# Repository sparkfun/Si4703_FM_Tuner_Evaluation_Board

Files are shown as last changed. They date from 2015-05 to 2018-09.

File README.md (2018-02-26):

SparkFun FM Tuner Evaluation Board - Si4703
===========================================

SparkFun FM Tuner Evaluation Board - Si4703  

[*SparkFun FM Tuner Evaluation Board - Si4703 (WRL-12938)*](https://www.sparkfun.com/products/12938)

This is an evaluation board for the Silicon Laboratories Si4703 FM tuner chip. Beyond being a simple FM radio, the Si4703 
is also capable of detecting and processing both Radio Data Service (RDS) and Radio Broadcast Data Service (RBDS) information. 

Repository Contents
-------------------
* **/Firmware** - Example code 
* **/Hardware** - Eagle design files (.brd, .sch)
* **/Libraries** - Libraries for use with the Si4703 Evaluation Board
* **/Production** - Production panel files (.brd)

Documentation
--------------
* **[Library](https://github.com/sparkfun/SparkFun_Si4703_Arduino_Library)** - Arduino and Raspberry Pi libraries for the Si4703.
* **[Hookup Guide](https://learn.sparkfun.com/tutorials/si4703-fm-radio-receiver-hookup-guide)** - Basic hookup guide for the Si4703.
* **[SparkFun Fritzing repo](https://github.com/sparkfun/Fritzing_Parts)** - Fritzing diagrams for SparkFun products.
* **[SparkFun 3D Model repo](https://github.com/sparkfun/3D_Models)** - 3D models of SparkFun products. 

License Information
-------------------
This product is _**open source**_! 

Please review the LICENSE.md file for license information. 

If you have any questions or concerns on licensing, please contact techsupport@sparkfun.com.

Distributed as-is; no warranty is given.

- Your friends at SparkFun.

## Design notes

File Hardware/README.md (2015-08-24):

SparkFun Si4703 Evaluation Board Design Files
============================================

The .sch and .brd files hare are Eagle CAD schematic and PCB design files from SparkFun Electronics.
A freeware version of Eagle can be found [here](http://www.cadsoftusa.com/download-eagle/freeware/). 

License
---------
This product is open source! 
The hardware is released under [Creative Commons ShareAlike 4.0 International](https://creativecommons.org/licenses/by-sa/4.0/).

Please use, reuse, and modify these files as you see fit. Please maintain attribution to SparkFun Electronics and release anything derivative under the same license.

Distributed as-is; no warranty is given.

- Your friends at SparkFun.

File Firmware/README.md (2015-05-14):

SparkFun Si4703 Firmware
===================================

* **Si4703_Example** - Arduino example

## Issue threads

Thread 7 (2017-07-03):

Polling during seek can impair receiver performance when using the internal oscillator

bigjosh, 2017-07-03:
From datasheet rev1.1...

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

Here is the polling code...
https://github.com/sparkfun/Si4703_FM_Tuner_Evaluation_Board/blob/master/Libraries/Arduino/src/SparkFunSi4703.cpp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

Ideal solution would be to generate an interrupt on seek completion, but this would add complexity and an extra pin.

Other options for mitigating could include....

* Adding a delay inside the loop so poll at least is not constantly banging on the bus at full blast. Increases code size slightly, and increases latency but a delay value of, say, 100ms likely not noticeable.
* Adding a length parameter to `readRegisters()` to reduce the amount of bus traffic. Since the seek function only needs to check register 0x0a to see if the STC bit is set, no need to read in all the other read registers on every poll. Slightly increases complexity.

LMK thoughts or if you want a PR for either or both.

bigjosh, 2018-02-27:
HI @nseidle !

I ended up forking and implementing both mitigation, but by now my fork is probably too far astray for an easy PR.

BTW, we empirically also found a few more issues with this chip - especially in the initialization timing. The problems are only an issue when you are using a lot of these chips and turning them on and off frequently. My current init code is here if you want to have a look...

https://github.com/bigjosh/Firmware/blob/no-led-pwm/Firmware/main.c#L489

It is a little messy right now because we were making changes on the fly as problems showed up in the field, but it has been stable for a few months now so I should clean it up.

I also ended up rewriting the TWI stuff from scratch to get everything to fit into an ATTINY25 (2K flash). That code is rock solid and much smaller and simpler than the old Atmel stuff....
https://github.com/bigjosh/Firmware/blob/no-led-pwm/Firmware/USI_TWI_Master.c

LMK if you are interested in any of this stuff and we can figure out the best way to get things merged.

nseidle, 2018-03-05:
What a super cool project! http://www.thepublicrad.io/

I agree - you have gone very hard core for a variety of good reasons. I would enjoy your improvements but you're rightly focused on ATtiny shoe-horning.

If you have a top 2 fix list that you could incorporate back into our lib that would be my ideal. But I imagine you've got other important things to work on. I'll keep this issue open so others can find your work.

Grahldg, 2018-09-12:
The latest release uses STC interrupts on GPIO2.  Suggestions from @bigjosh above to add a delay or only poll the appropriate register can also be used if anyone would like to increase tuning accuracy without the use of additional pin.

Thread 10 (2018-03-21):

No need the wait after Wire.requestFrom().

Koepel, 2018-03-21:
The line `while(Wire.available() < 32) ;` after the Wire.requestFrom() can be removed in:
- Si4703_FM_Tuner_Evaluation_Board/Firmware/Si4703_Example/Si4703_Example.ino
- Si4703_FM_Tuner_Evaluation_Board/Libraries/Arduino/src/SparkFunSi4703.cpp

When the Wire.requestFrom() returns, the I2C transaction on the bus has completely finished and the received data is waiting in a buffer in the Wire library. There is no need to wait for something.

Grahldg, 2018-09-10:
Hi @Koepel ,

I removed both instances as well as one in the [Arduino Library](https://github.com/sparkfun/SparkFun_Si4703_Arduino_Library).

Closed 2018-09-10.

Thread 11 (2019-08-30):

Seems RDS reading doesn't work with arduino

moznion, 2019-08-30:
Hi,

I've tried to run the `Si4703_Radio_Test` example with the Si4703 break board on Arduino.
It seems sound receiving works certainly, but RDS reading (i.e. send `r` key via serial) doesn't work certainly; it means the `rdsBuffer` is empty. On the other hand, the real radio product can receive the RDS text correctly.
In my investigation, `STATUSRSSI` register's `RDSR` bit **never** be high even if the RDS text is on the wave.

FYI, I've used Si4713 chip as the FM transmitter with this library: https://github.com/adafruit/Adafruit-Si4713-Library

What do you think about this problem?

Incidentally, I modified the library code to change it be suitable to use in Japan. The diff is the following:

```diff
diff --git a/Libraries/Arduino/src/SparkFunSi4703.cpp b/Libraries/Arduino/src/SparkFunSi4703.cpp
index 2e5cd7e..aaa2f44 100644
--- a/Libraries/Arduino/src/SparkFunSi4703.cpp
+++ b/Libraries/Arduino/src/SparkFunSi4703.cpp
@@ -17,12 +17,12 @@ void Si4703_Breakout::powerOn()

 void Si4703_Breakout::setChannel(int channel)
 {
-  //Freq(MHz) = 0.200(in USA) * Channel + 87.5MHz
-  //97.3 = 0.2 * Chan + 87.5
-  //9.8 / 0.2 = 49
-  int newChannel = channel * 10; //973 * 10 = 9730
-  newChannel -= 8750; //9730 - 8750 = 980
-  newChannel /= 10; //980 / 10 = 98
+  // Freq(MHz) = 0.100(in Japan) * Channel + 76.0MHz
+  // 80.0 = 0.1 * Chan + 76.0
+  // 4.0 / 0.1 = 40
+  int newChannel = channel * 10; // 800 * 10 = 8000
+  newChannel -= 7600;            // 8000 - 7600 = 400
+  newChannel /= 10;              // 400 / 10 = 40
@@ -113,7 +114,7 @@ void Si4703_Breakout::readRDS(char* buffer, long timeout)
 //To get the Si4703 inito 2-wire mode, SEN needs to be high and SDIO needs to be low after a reset
 //The breakout board has SEN pulled high, but also has SDIO pulled high. Therefore, after a normal power up
 //The Si4703 will be in an unknown state. RST must be controlled
-void Si4703_Breakout::si4703_init()
+void Si4703_Breakout::si4703_init()
 {
   pinMode(_resetPin, OUTPUT);
   pinMode(_sdioPin, OUTPUT); //SDIO is connected to A4 for I2C
@@ -141,10 +142,12 @@ void Si4703_Breakout::si4703_init()
   si4703_registers[SYSCONFIG1] |= (1<<RDS); //Enable RDS

   si4703_registers[SYSCONFIG1] |= (1<<DE); //50kHz Europe setup
-  si4703_registers[SYSCONFIG2] |= (1<<SPACE0); //100kHz channel spacing for Europe
+  si4703_registers[SYSCONFIG2] |= (1<<SPACE0); //100kHz channel spacing for Japan
+  si4703_registers[SYSCONFIG2] |= (1<<JP_WIDE_BAND);

   si4703_registers[SYSCONFIG2] &= 0xFFF0; //Clear volume bits
   si4703_registers[SYSCONFIG2] |= 0x0001; //Set volume to lowest
+
   updateRegisters(); //Update

   delay(110); //Max powerup time, from datasheet page 13
@@ -184,7 +187,7 @@ byte Si4703_Breakout::updateRegisters() {

   //End this transmission
   byte ack = Wire.endTransmission();
-  if(ack != 0) { //We have a problem!
+  if(ack != 0) { //We have a problem!
     return(FAIL);
   }
@@ -229,8 +232,8 @@ return getChannel();
 int Si4703_Breakout::getChannel() {
   readRegisters();
   int channel = si4703_registers[READCHAN] & 0x03FF; //Mask out e
verything but the lower 10 bits
-  //Freq(MHz) = 0.100(in Europe) * Channel + 87.5MHz
-  //X = 0.1 * Chan + 87.5
-  channel += 875; //98 + 875 = 973
+  // Freq(MHz) = 0.100(in Japan) * Channel + 76.0MHz
+  // X = 0.1 * Chan + 76.0
+  channel += 760; // 40 + 760 = 800
   return(channel);
 }
```

† JP_WIDE_BAND=6

inpatol, 2023-06-18:
Hi, have you found a solution for this? I am having the same problem in argentina.

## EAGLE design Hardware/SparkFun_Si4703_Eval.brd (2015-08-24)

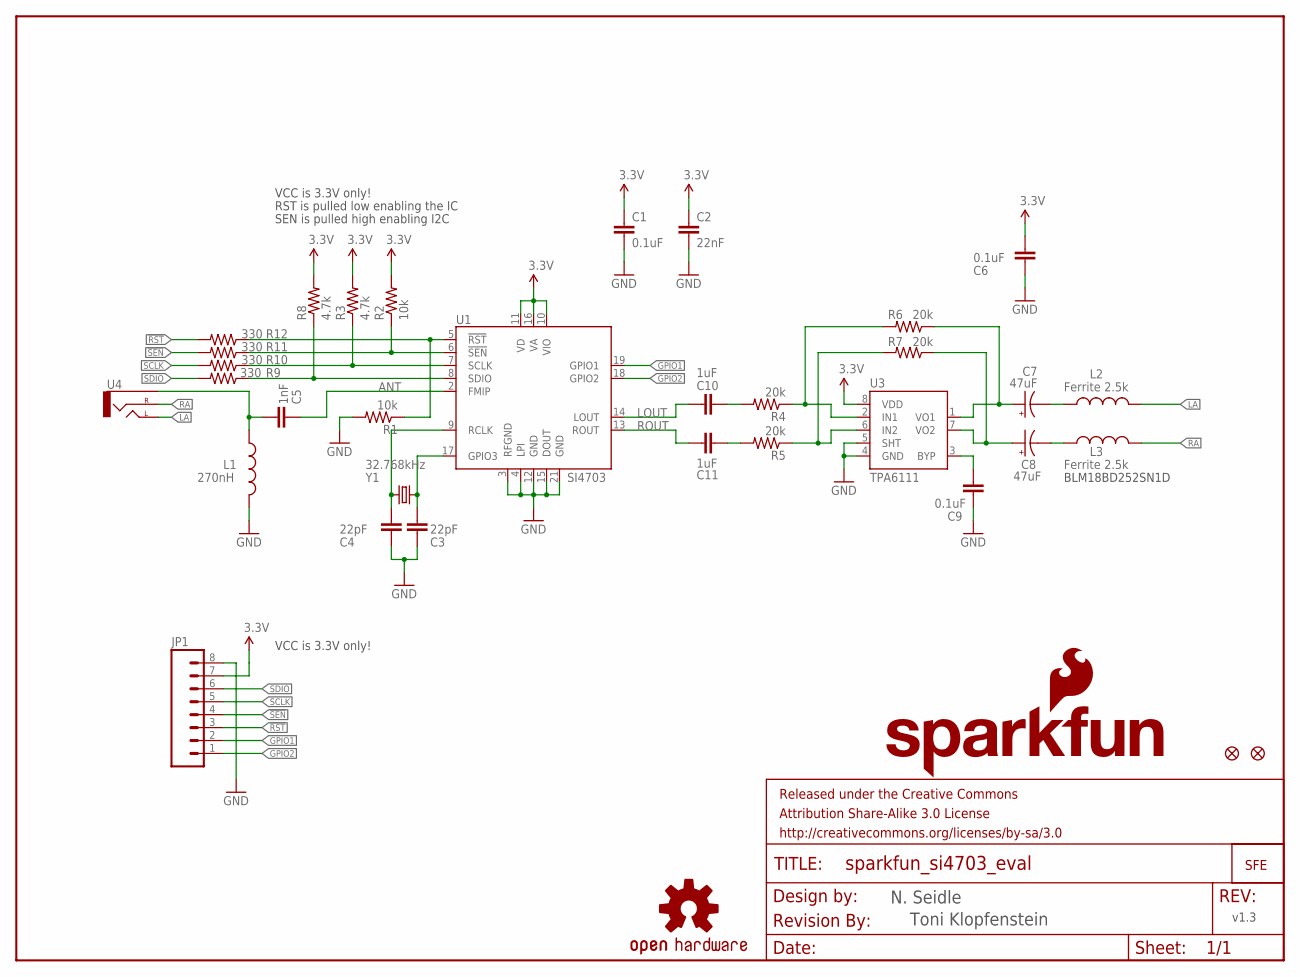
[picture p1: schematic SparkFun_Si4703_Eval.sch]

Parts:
C1, C6, C9: 0.1uF; 0603-CAP
C2: 22nF; 0603-CAP
C3, C4: 22pF; 0603-CAP
C5: 1nF; 0603-CAP
C7, C8: 47uF; EIA3528
C10, C11: 1uF; 0603-CAP
FRAME2: FRAME-LETTER; CREATIVE_COMMONS
JP1: M08; 1X08
JP3: LOGO-SFESK; SFE-LOGO-FLAME
JP4, JP5: FIDUCIAL1X2; FIDUCIAL-1X2
L1: 270nH; 0603
L2, L3: Ferrite 2.5k; 0603
LOGO1: SFE_LOGO_NAME_FLAME.1_INCH; SFE_LOGO_NAME_FLAME_.1
LOGO2: OSHW-LOGOS; OSHW-LOGO-S
R1, R2: 10k; 0603-RES
R3, R8: 4.7k; 0603
R4, R5, R6, R7: 20k; 0603-RES
R9, R10, R11, R12: 330; 0603-RES
U1: SI4703; SI470X
U3: TPA6111; SO08-TIGHT
U4: AUDIO-JACKSMD2; AUDIO-JACK-3.5MM-SMD
U$1: REVISION
Y1: 32.768kHz; CRYSTAL-32KHZ-SMD

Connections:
3.3V: C1.1, C2.1, C6.2, JP1.7, R2.2, R3.2, R8.2, U1.10 (VIO), U1.11 (VD), U1.16 (VA), U3.8 (VDD)
!RST: JP1.3, R12.2
!RST-L: R1.1, R12.1, U1.5 (!RST)
!SEN: JP1.4, R11.2
!SEN-L: R2.1, R11.1, U1.6 (!SEN)
ANT: C5.1, U1.2 (FMIP)
GND: C1.2, C2.2, C3.1, C4.1, C6.1, C9.2, JP1.8, L1.2, R1.2, U1.3 (RFGND), U1.4 (LPI), U1.12 (GND), U1.15 (DOUT), U1.21 (GND), U3.4 (GND), U3.5 (SHT)
GPIO1: JP1.2, U1.19 (GPIO1)
GPIO2: JP1.1, U1.18 (GPIO2)
LA: L2.2, U4.TIP (LEFT)
LOUT: C10.1, U1.14 (LOUT)
unnamed: C4.2, U1.9 (RCLK), Y1.X2 (2)
unnamed: C3.2, U1.17 (GPIO3), Y1.X1 (1)
unnamed: C5.2, L1.1, U4.SLEEVE
unnamed: C7.C (-), L2.1
unnamed: C7.A (+), R6.1, U3.1 (VO1)
unnamed: C8.A (+), R7.1, U3.7 (VO2)
unnamed: C8.C (-), L3.1
unnamed: C9.1, U3.3 (BYP)
unnamed: R4.1, R6.2, U3.2 (IN1)
unnamed: R5.1, R7.2, U3.6 (IN2)
unnamed: C10.2, R4.2
unnamed: C11.2, R5.2
RA: L3.2, U4.RING (RIGHT)
ROUT: C11.1, U1.13 (ROUT)
SCLK: JP1.5, R10.2
SCLK-L: R3.1, R10.1, U1.7 (SCLK)
SDIO: JP1.6, R9.2
SDIO-L: R8.1, R9.1, U1.8 (SDIO)

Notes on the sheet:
VCC is 3.3V only!
N. Seidle
BLM18BD252SN1D
SEN is pulled high enabling I2C
RST is pulled low enabling the IC
v1.3
Toni Klopfenstein

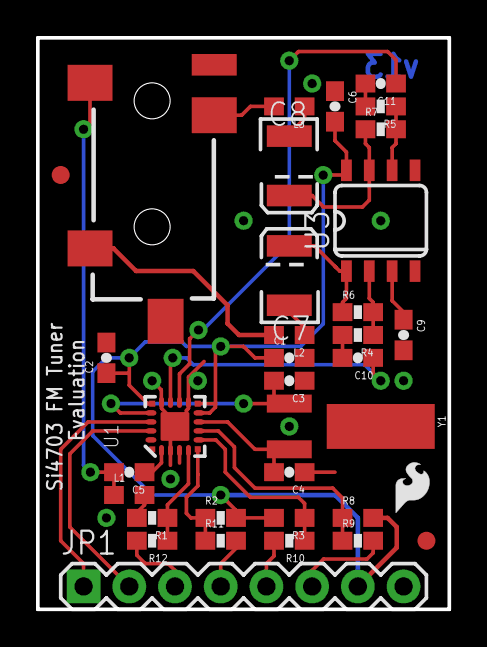
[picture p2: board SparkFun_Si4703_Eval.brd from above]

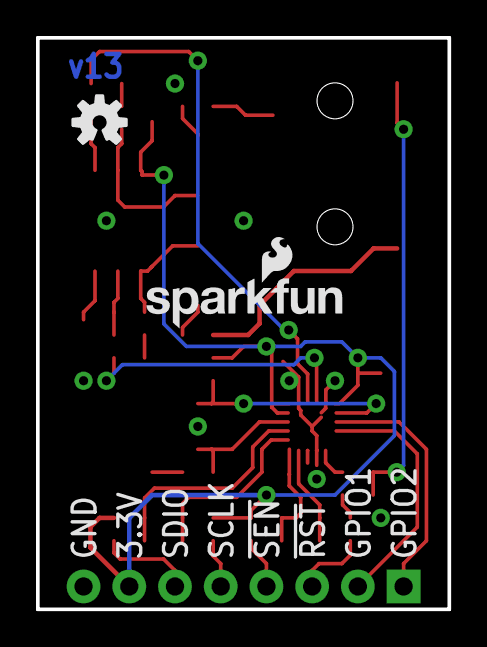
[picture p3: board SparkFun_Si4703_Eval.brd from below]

Board: 2 copper layers, 22.9 x 31.8 mm, 38 parts (2 on the bottom side), 29 nets.

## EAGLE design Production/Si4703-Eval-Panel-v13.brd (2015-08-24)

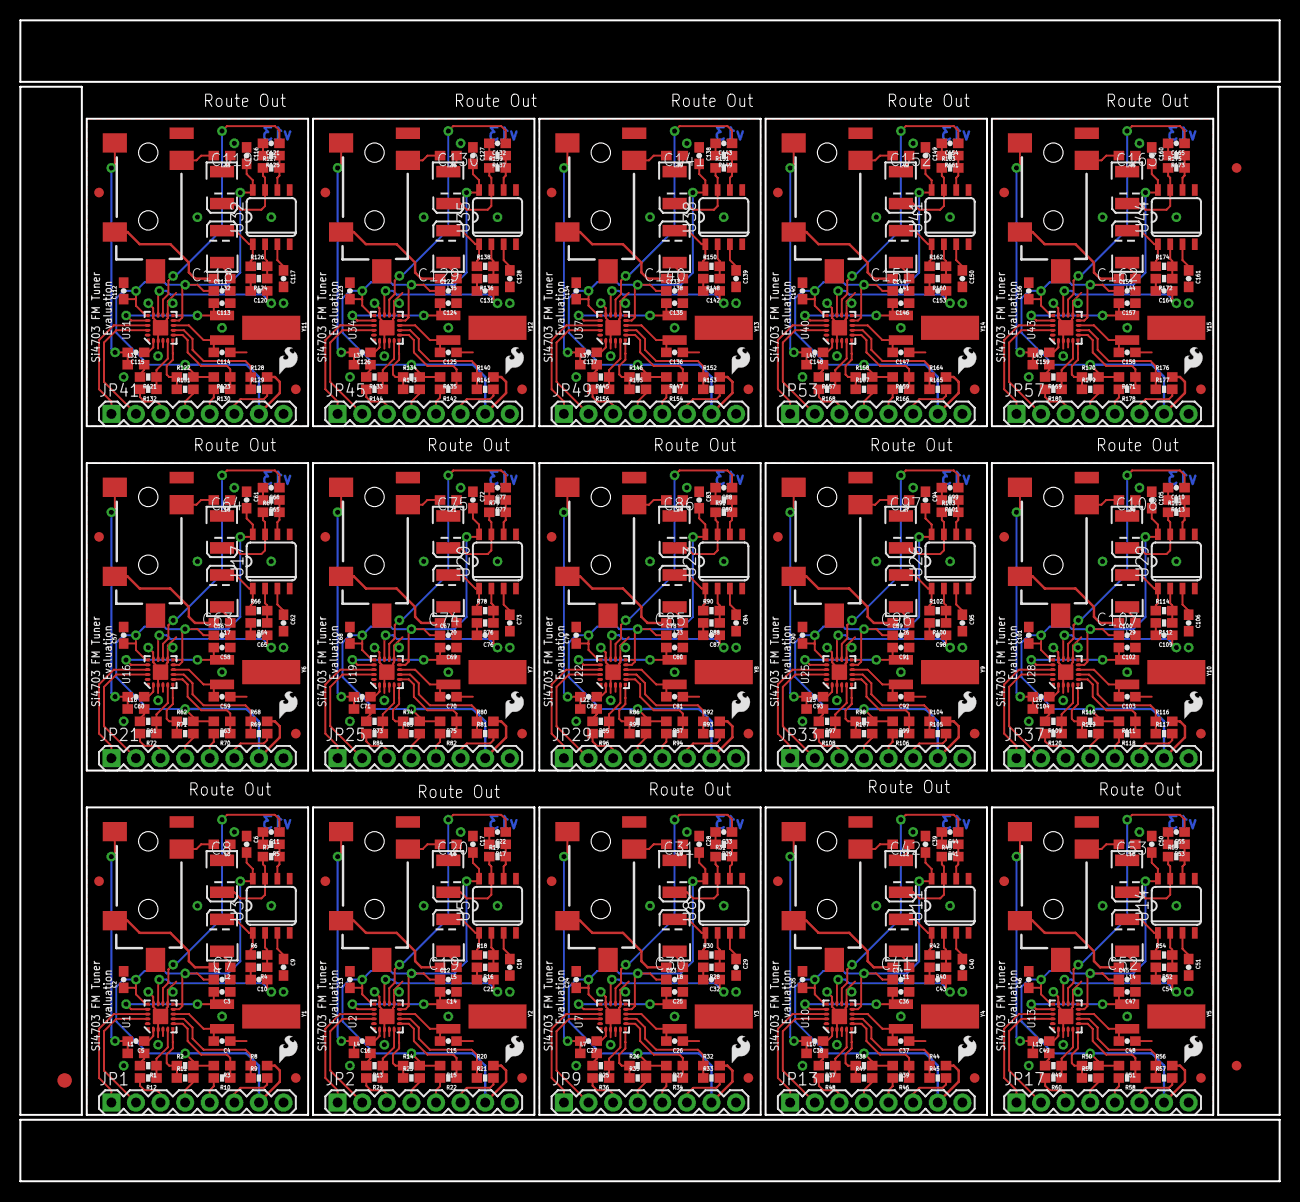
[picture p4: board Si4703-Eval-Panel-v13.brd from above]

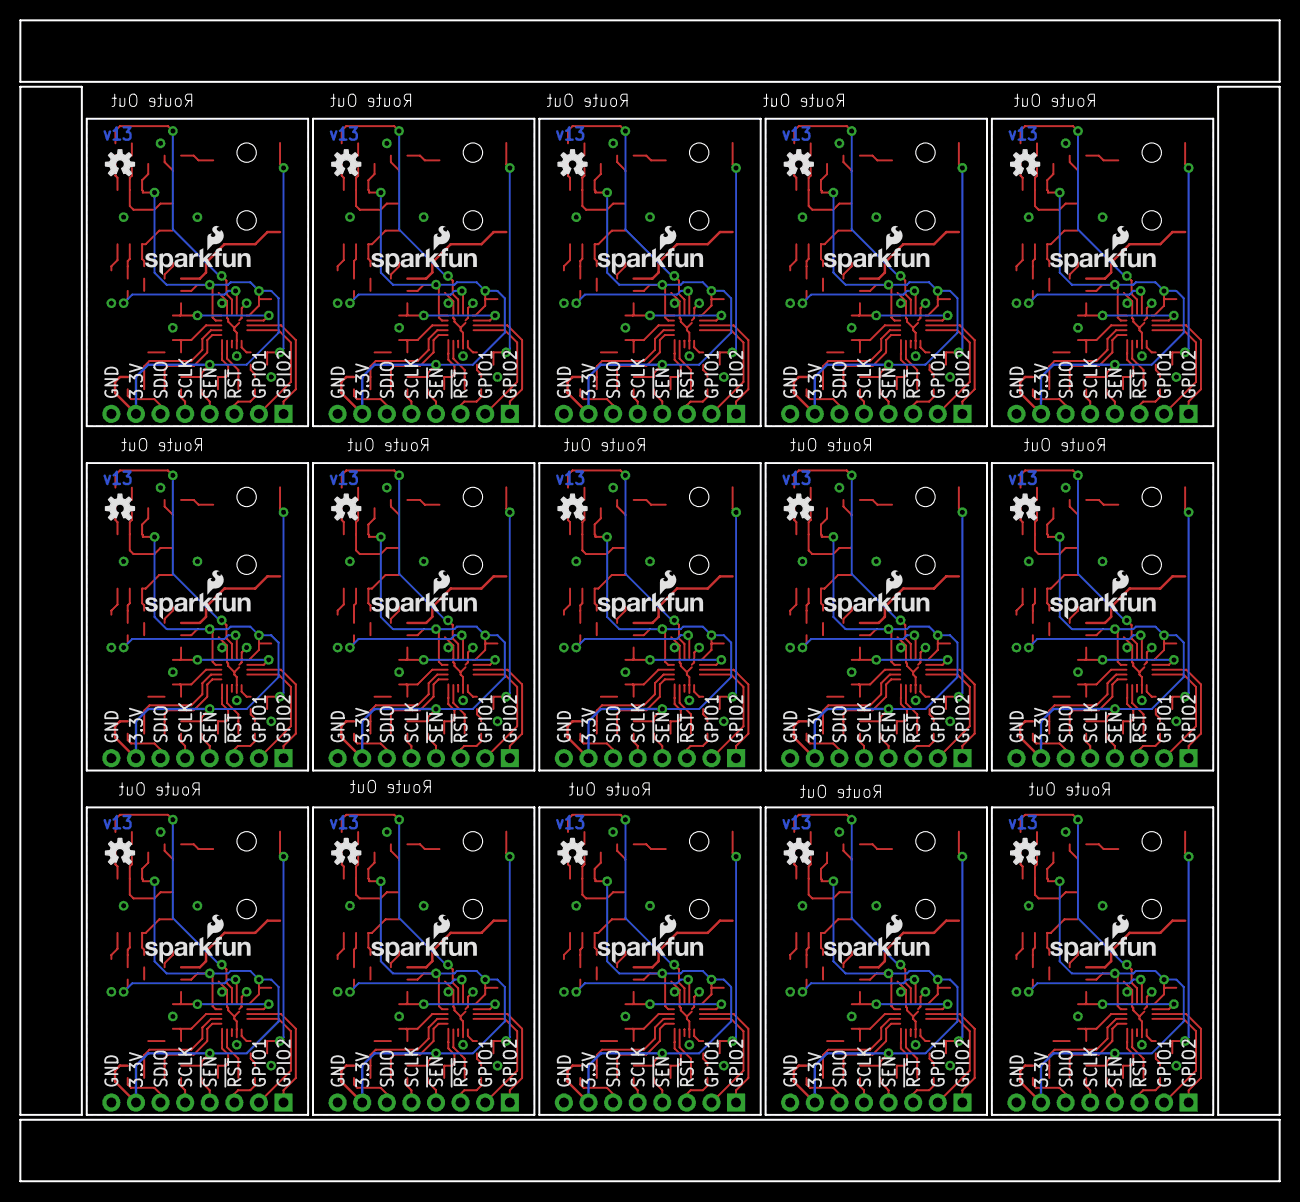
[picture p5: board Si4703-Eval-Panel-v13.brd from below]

Board: 2 copper layers, 130.0 x 119.9 mm, 543 parts (30 on the bottom side), 435 nets.

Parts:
C1, C6, C9, C12, C17, C18, C23, C28, C29, C34, C39, C40, C45, C50, C51, C56, C61, C62, C67, C72, C73, C78, C83, C84, C89, C94, C95, C100, C105, C106, C111, C116, C117, C122, C127, C128, C133, C138, C139, C144, C149, C150, C155, C160, C161: 0.1uF; 0603-CAP
C2, C13, C24, C35, C46, C57, C68, C79, C90, C101, C112, C123, C134, C145, C156: 22nF; 0603-CAP
C3, C4, C14, C15, C25, C26, C36, C37, C47, C48, C58, C59, C69, C70, C80, C81, C91, C92, C102, C103, C113, C114, C124, C125, C135, C136, C146, C147, C157, C158: 22pF; 0603-CAP
C5, C16, C27, C38, C49, C60, C71, C82, C93, C104, C115, C126, C137, C148, C159: 1nF; 0603-CAP
C7, C8, C19, C20, C30, C31, C41, C42, C52, C53, C63, C64, C74, C75, C85, C86, C96, C97, C107, C108, C118, C119, C129, C130, C140, C141, C151, C152, C162, C163: 47uF; EIA3528
C10, C11, C21, C22, C32, C33, C43, C44, C54, C55, C65, C66, C76, C77, C87, C88, C98, C99, C109, C110, C120, C121, C131, C132, C142, C143, C153, C154, C164, C165: 1uF; 0603-CAP
E$1: FIDUCIAL-1.5X3
E$4, E$5: FIDUCIAL-1X2
JP1, JP2, JP9, JP13, JP17, JP21, JP25, JP29, JP33, JP37, JP41, JP45, JP49, JP53, JP57: 1X08
JP3, JP6, JP10, JP14, JP18, JP22, JP26, JP30, JP34, JP38, JP42, JP46, JP50, JP54, JP58: LOGO-SFESK; SFE-LOGO-FLAME
JP4, JP5, JP7, JP8, JP11, JP12, JP15, JP16, JP19, JP20, JP23, JP24, JP27, JP28, JP31, JP32, JP35, JP36, JP39, JP40, JP43, JP44, JP47, JP48, JP51, JP52, JP55, JP56, JP59, JP60: FIDUCIAL1X2; FIDUCIAL-1X2
L1, L4, L7, L10, L13, L16, L19, L22, L25, L28, L31, L34, L37, L40, L43: 270nH; 0603
L2, L3, L5, L6, L8, L9, L11, L12, L14, L15, L17, L18, L20, L21, L23, L24, L26, L27, L29, L30, L32, L33, L35, L36, L38, L39, L41, L42, L44, L45: Ferrite 2.5k; 0603
LOGO1, LOGO3, LOGO5, LOGO7, LOGO9, LOGO11, LOGO13, LOGO15, LOGO17, LOGO19, LOGO21, LOGO23, LOGO25, LOGO27, LOGO29: SFE_LOGO_NAME_FLAME.1_INCH; SFE_LOGO_NAME_FLAME_.1
LOGO2, LOGO4, LOGO6, LOGO8, LOGO10, LOGO12, LOGO14, LOGO16, LOGO18, LOGO20, LOGO22, LOGO24, LOGO26, LOGO28, LOGO30: OSHW-LOGOS; OSHW-LOGO-S
R1, R2, R13, R14, R25, R26, R37, R38, R49, R50, R61, R62, R73, R74, R85, R86, R97, R98, R109, R110, R121, R122, R133, R134, R145, R146, R157, R158, R169, R170: 10k; 0603-RES
R3, R8, R15, R20, R27, R32, R39, R44, R51, R56, R63, R68, R75, R80, R87, R92, R99, R104, R111, R116, R123, R128, R135, R140, R147, R152, R159, R164, R171, R176: 4.7k; 0603
R4, R5, R6, R7, R16, R17, R18, R19, R28, R29, R30, R31, R40, R41, R42, R43, R52, R53, R54, R55, R64, R65, R66, R67, R76, R77, R78, R79, R88, R89, R90, R91, R100, R101, R102, R103, R112, R113, R114, R115, R124, R125, R126, R127, R136, R137, R138, R139, R148, R149, R150, R151, R160, R161, R162, R163, R172, R173, R174, R175: 20k; 0603-RES
R9, R10, R11, R12, R21, R22, R23, R24, R33, R34, R35, R36, R45, R46, R47, R48, R57, R58, R59, R60, R69, R70, R71, R72, R81, R82, R83, R84, R93, R94, R95, R96, R105, R106, R107, R108, R117, R118, R119, R120, R129, R130, R131, R132, R141, R142, R143, R144, R153, R154, R155, R156, R165, R166, R167, R168, R177, R178, R179, R180: 330; 0603-RES
U1, U2, U7, U10, U13, U16, U19, U22, U25, U28, U31, U34, U37, U40, U43: SI4703; SI470X
U3, U5, U8, U11, U14, U17, U20, U23, U26, U29, U32, U35, U38, U41, U44: TPA6111; SO08-TIGHT
U4, U6, U9, U12, U15, U18, U21, U24, U27, U30, U33, U36, U39, U42, U45: AUDIO-JACK-3.5MM-SMD
Y1, Y2, Y3, Y4, Y5, Y6, Y7, Y8, Y9, Y10, Y11, Y12, Y13, Y14, Y15: 32.768kHz; CRYSTAL-32KHZ-SMD

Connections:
3.3V: C1.1, C2.1, C6.2, JP1.7, R2.2, R3.2, R8.2, U1.10, U1.11, U1.16, U3.8
3.3V1: C12.1, C13.1, C17.2, JP2.7, R14.2, R15.2, R20.2, U2.10, U2.11, U2.16, U5.8
3.3V2: C23.1, C24.1, C28.2, JP9.7, R26.2, R27.2, R32.2, U7.10, U7.11, U7.16, U8.8
3.3V3: C34.1, C35.1, C39.2, JP13.7, R38.2, R39.2, R44.2, U10.10, U10.11, U10.16, U11.8
3.3V4: C45.1, C46.1, C50.2, JP17.7, R50.2, R51.2, R56.2, U13.10, U13.11, U13.16, U14.8
3.3V5: C56.1, C57.1, C61.2, JP21.7, R62.2, R63.2, R68.2, U16.10, U16.11, U16.16, U17.8
3.3V6: C67.1, C68.1, C72.2, JP25.7, R74.2, R75.2, R80.2, U19.10, U19.11, U19.16, U20.8
3.3V7: C78.1, C79.1, C83.2, JP29.7, R86.2, R87.2, R92.2, U22.10, U22.11, U22.16, U23.8
3.3V8: C89.1, C90.1, C94.2, JP33.7, R98.2, R99.2, R104.2, U25.10, U25.11, U25.16, U26.8
3.3V9: C100.1, C101.1, C105.2, JP37.7, R110.2, R111.2, R116.2, U28.10, U28.11, U28.16, U29.8
3.3V10: C111.1, C112.1, C116.2, JP41.7, R122.2, R123.2, R128.2, U31.10, U31.11, U31.16, U32.8
3.3V11: C122.1, C123.1, C127.2, JP45.7, R134.2, R135.2, R140.2, U34.10, U34.11, U34.16, U35.8
3.3V12: C133.1, C134.1, C138.2, JP49.7, R146.2, R147.2, R152.2, U37.10, U37.11, U37.16, U38.8
3.3V13: C144.1, C145.1, C149.2, JP53.7, R158.2, R159.2, R164.2, U40.10, U40.11, U40.16, U41.8
3.3V14: C155.1, C156.1, C160.2, JP57.7, R170.2, R171.2, R176.2, U43.10, U43.11, U43.16, U44.8
!RST: JP1.3, R12.2
!RST1: JP2.3, R24.2
!RST2: JP9.3, R36.2
!RST3: JP13.3, R48.2
!RST4: JP17.3, R60.2
!RST5: JP21.3, R72.2
!RST6: JP25.3, R84.2
!RST7: JP29.3, R96.2
!RST8: JP33.3, R108.2
!RST9: JP37.3, R120.2
!RST10: JP41.3, R132.2
!RST11: JP45.3, R144.2
!RST12: JP49.3, R156.2
!RST13: JP53.3, R168.2
!RST14: JP57.3, R180.2
!RST-L: R1.1, R12.1, U1.5
!RST-L1: R13.1, R24.1, U2.5
!RST-L2: R25.1, R36.1, U7.5
!RST-L3: R37.1, R48.1, U10.5
!RST-L4: R49.1, R60.1, U13.5
!RST-L5: R61.1, R72.1, U16.5
!RST-L6: R73.1, R84.1, U19.5
!RST-L7: R85.1, R96.1, U22.5
!RST-L8: R97.1, R108.1, U25.5
!RST-L9: R109.1, R120.1, U28.5
!RST-L10: R121.1, R132.1, U31.5
!RST-L11: R133.1, R144.1, U34.5
!RST-L12: R145.1, R156.1, U37.5
!RST-L13: R157.1, R168.1, U40.5
!RST-L14: R169.1, R180.1, U43.5
!SEN: JP1.4, R11.2
!SEN1: JP2.4, R23.2
!SEN2: JP9.4, R35.2
!SEN3: JP13.4, R47.2
!SEN4: JP17.4, R59.2
!SEN5: JP21.4, R71.2
!SEN6: JP25.4, R83.2
!SEN7: JP29.4, R95.2
!SEN8: JP33.4, R107.2
!SEN9: JP37.4, R119.2
!SEN10: JP41.4, R131.2
!SEN11: JP45.4, R143.2
!SEN12: JP49.4, R155.2
!SEN13: JP53.4, R167.2
!SEN14: JP57.4, R179.2
!SEN-L: R2.1, R11.1, U1.6
!SEN-L1: R14.1, R23.1, U2.6
!SEN-L2: R26.1, R35.1, U7.6
!SEN-L3: R38.1, R47.1, U10.6
!SEN-L4: R50.1, R59.1, U13.6
!SEN-L5: R62.1, R71.1, U16.6
!SEN-L6: R74.1, R83.1, U19.6
!SEN-L7: R86.1, R95.1, U22.6
!SEN-L8: R98.1, R107.1, U25.6
!SEN-L9: R110.1, R119.1, U28.6
!SEN-L10: R122.1, R131.1, U31.6
!SEN-L11: R134.1, R143.1, U34.6
!SEN-L12: R146.1, R155.1, U37.6
!SEN-L13: R158.1, R167.1, U40.6
!SEN-L14: R170.1, R179.1, U43.6
ANT: C5.1, U1.2
ANT1: C16.1, U2.2
ANT2: C27.1, U7.2
ANT3: C38.1, U10.2
ANT4: C49.1, U13.2
ANT5: C60.1, U16.2
ANT6: C71.1, U19.2
ANT7: C82.1, U22.2
ANT8: C93.1, U25.2
ANT9: C104.1, U28.2
ANT10: C115.1, U31.2
ANT11: C126.1, U34.2
ANT12: C137.1, U37.2
ANT13: C148.1, U40.2
ANT14: C159.1, U43.2
GND: C1.2, C2.2, C3.1, C4.1, C6.1, C9.2, JP1.8, L1.2, R1.2, U1.3, U1.4, U1.12, U1.15, U1.21, U3.4, U3.5
GND1: C12.2, C13.2, C14.1, C15.1, C17.1, C18.2, JP2.8, L4.2, R13.2, U2.3, U2.4, U2.12, U2.15, U2.21, U5.4, U5.5
GND2: C23.2, C24.2, C25.1, C26.1, C28.1, C29.2, JP9.8, L7.2, R25.2, U7.3, U7.4, U7.12, U7.15, U7.21, U8.4, U8.5
GND3: C34.2, C35.2, C36.1, C37.1, C39.1, C40.2, JP13.8, L10.2, R37.2, U10.3, U10.4, U10.12, U10.15, U10.21, U11.4, U11.5
GND4: C45.2, C46.2, C47.1, C48.1, C50.1, C51.2, JP17.8, L13.2, R49.2, U13.3, U13.4, U13.12, U13.15, U13.21, U14.4, U14.5
GND5: C56.2, C57.2, C58.1, C59.1, C61.1, C62.2, JP21.8, L16.2, R61.2, U16.3, U16.4, U16.12, U16.15, U16.21, U17.4, U17.5
GND6: C67.2, C68.2, C69.1, C70.1, C72.1, C73.2, JP25.8, L19.2, R73.2, U19.3, U19.4, U19.12, U19.15, U19.21, U20.4, U20.5
GND7: C78.2, C79.2, C80.1, C81.1, C83.1, C84.2, JP29.8, L22.2, R85.2, U22.3, U22.4, U22.12, U22.15, U22.21, U23.4, U23.5
GND8: C89.2, C90.2, C91.1, C92.1, C94.1, C95.2, JP33.8, L25.2, R97.2, U25.3, U25.4, U25.12, U25.15, U25.21, U26.4, U26.5
GND9: C100.2, C101.2, C102.1, C103.1, C105.1, C106.2, JP37.8, L28.2, R109.2, U28.3, U28.4, U28.12, U28.15, U28.21, U29.4, U29.5
GND10: C111.2, C112.2, C113.1, C114.1, C116.1, C117.2, JP41.8, L31.2, R121.2, U31.3, U31.4, U31.12, U31.15, U31.21, U32.4, U32.5
GND11: C122.2, C123.2, C124.1, C125.1, C127.1, C128.2, JP45.8, L34.2, R133.2, U34.3, U34.4, U34.12, U34.15, U34.21, U35.4, U35.5
GND12: C133.2, C134.2, C135.1, C136.1, C138.1, C139.2, JP49.8, L37.2, R145.2, U37.3, U37.4, U37.12, U37.15, U37.21, U38.4, U38.5
GND13: C144.2, C145.2, C146.1, C147.1, C149.1, C150.2, JP53.8, L40.2, R157.2, U40.3, U40.4, U40.12, U40.15, U40.21, U41.4, U41.5
GND14: C155.2, C156.2, C157.1, C158.1, C160.1, C161.2, JP57.8, L43.2, R169.2, U43.3, U43.4, U43.12, U43.15, U43.21, U44.4, U44.5
GPIO1: JP1.2, U1.19
GPIO2: JP1.1, U1.18
GPIO3: JP2.2, U2.19
GPIO4: JP2.1, U2.18
GPIO5: JP9.2, U7.19
GPIO6: JP9.1, U7.18
GPIO7: JP13.2, U10.19
GPIO8: JP13.1, U10.18
GPIO9: JP17.2, U13.19
GPIO10: JP17.1, U13.18
GPIO11: JP21.2, U16.19
GPIO12: JP21.1, U16.18
GPIO13: JP25.2, U19.19
GPIO14: JP25.1, U19.18
GPIO15: JP29.2, U22.19
GPIO16: JP29.1, U22.18
GPIO17: JP33.2, U25.19
GPIO18: JP33.1, U25.18
GPIO19: JP37.2, U28.19
GPIO20: JP37.1, U28.18
GPIO21: JP41.2, U31.19
GPIO22: JP41.1, U31.18
GPIO23: JP45.2, U34.19
GPIO24: JP45.1, U34.18
GPIO25: JP49.2, U37.19
GPIO26: JP49.1, U37.18
GPIO27: JP53.2, U40.19
GPIO28: JP53.1, U40.18
GPIO29: JP57.2, U43.19
GPIO30: JP57.1, U43.18
LA: L2.2, U4.TIP
LA1: L5.2, U6.TIP
LA2: L8.2, U9.TIP
LA3: L11.2, U12.TIP
LA4: L14.2, U15.TIP
LA5: L17.2, U18.TIP
LA6: L20.2, U21.TIP
LA7: L23.2, U24.TIP
LA8: L26.2, U27.TIP
LA9: L29.2, U30.TIP
LA10: L32.2, U33.TIP
LA11: L35.2, U36.TIP
LA12: L38.2, U39.TIP
LA13: L41.2, U42.TIP
LA14: L44.2, U45.TIP
LOUT: C10.1, U1.14
LOUT1: C21.1, U2.14
LOUT2: C32.1, U7.14
LOUT3: C43.1, U10.14
LOUT4: C54.1, U13.14
LOUT5: C65.1, U16.14
LOUT6: C76.1, U19.14
LOUT7: C87.1, U22.14
LOUT8: C98.1, U25.14
LOUT9: C109.1, U28.14
LOUT10: C120.1, U31.14
LOUT11: C131.1, U34.14
LOUT12: C142.1, U37.14
LOUT13: C153.1, U40.14
LOUT14: C164.1, U43.14
unnamed: C4.2, U1.9, Y1.X2
unnamed: C3.2, U1.17, Y1.X1
unnamed: C5.2, L1.1, U4.SLEEVE
unnamed: C7.C, L2.1
unnamed: C7.A, R6.1, U3.1
unnamed: C8.A, R7.1, U3.7
unnamed: C8.C, L3.1
unnamed: C9.1, U3.3
unnamed: C15.2, U2.9, Y2.X2
unnamed: C14.2, U2.17, Y2.X1
unnamed: R4.1, R6.2, U3.2
unnamed: R5.1, R7.2, U3.6
unnamed: C10.2, R4.2
unnamed: C11.2, R5.2
unnamed: C16.2, L4.1, U6.SLEEVE
unnamed: C19.A, R18.1, U5.1
unnamed: C20.A, R19.1, U5.7
unnamed: C18.1, U5.3
unnamed: R16.1, R18.2, U5.2
unnamed: R17.1, R19.2, U5.6
unnamed: C21.2, R16.2
unnamed: C22.2, R17.2
unnamed: C19.C, L5.1
unnamed: C20.C, L6.1
unnamed: C26.2, U7.9, Y3.X2
unnamed: C25.2, U7.17, Y3.X1
unnamed: C27.2, L7.1, U9.SLEEVE
unnamed: C30.A, R30.1, U8.1
unnamed: C31.A, R31.1, U8.7
unnamed: C29.1, U8.3
unnamed: R28.1, R30.2, U8.2
unnamed: R29.1, R31.2, U8.6
unnamed: C32.2, R28.2
unnamed: C33.2, R29.2
unnamed: C30.C, L8.1
unnamed: C31.C, L9.1
unnamed: C37.2, U10.9, Y4.X2
unnamed: C36.2, U10.17, Y4.X1
unnamed: C38.2, L10.1, U12.SLEEVE
unnamed: C41.A, R42.1, U11.1
unnamed: C42.A, R43.1, U11.7
unnamed: C40.1, U11.3
unnamed: R40.1, R42.2, U11.2
unnamed: R41.1, R43.2, U11.6
unnamed: C43.2, R40.2
unnamed: C44.2, R41.2
unnamed: C41.C, L11.1
unnamed: C42.C, L12.1
unnamed: C48.2, U13.9, Y5.X2
unnamed: C47.2, U13.17, Y5.X1
unnamed: C49.2, L13.1, U15.SLEEVE
unnamed: C52.A, R54.1, U14.1
unnamed: C53.A, R55.1, U14.7
unnamed: C51.1, U14.3
unnamed: R52.1, R54.2, U14.2
unnamed: R53.1, R55.2, U14.6
unnamed: C54.2, R52.2
unnamed: C55.2, R53.2
unnamed: C52.C, L14.1
unnamed: C53.C, L15.1
unnamed: C59.2, U16.9, Y6.X2
unnamed: C58.2, U16.17, Y6.X1
unnamed: C60.2, L16.1, U18.SLEEVE
unnamed: C63.A, R66.1, U17.1
unnamed: C64.A, R67.1, U17.7
unnamed: C62.1, U17.3
unnamed: R64.1, R66.2, U17.2
unnamed: R65.1, R67.2, U17.6
unnamed: C65.2, R64.2
unnamed: C66.2, R65.2
unnamed: C63.C, L17.1
unnamed: C64.C, L18.1
unnamed: C70.2, U19.9, Y7.X2
unnamed: C69.2, U19.17, Y7.X1
unnamed: C71.2, L19.1, U21.SLEEVE
unnamed: C74.A, R78.1, U20.1
unnamed: C75.A, R79.1, U20.7
unnamed: C73.1, U20.3
unnamed: R76.1, R78.2, U20.2
unnamed: R77.1, R79.2, U20.6
unnamed: C76.2, R76.2
unnamed: C77.2, R77.2
unnamed: C74.C, L20.1
unnamed: C75.C, L21.1
unnamed: C81.2, U22.9, Y8.X2
unnamed: C80.2, U22.17, Y8.X1
unnamed: C82.2, L22.1, U24.SLEEVE
unnamed: C85.A, R90.1, U23.1
unnamed: C86.A, R91.1, U23.7
unnamed: C84.1, U23.3
unnamed: R88.1, R90.2, U23.2
unnamed: R89.1, R91.2, U23.6
unnamed: C87.2, R88.2
unnamed: C88.2, R89.2
unnamed: C85.C, L23.1
unnamed: C86.C, L24.1
unnamed: C92.2, U25.9, Y9.X2
unnamed: C91.2, U25.17, Y9.X1
unnamed: C93.2, L25.1, U27.SLEEVE
unnamed: C96.A, R102.1, U26.1
unnamed: C97.A, R103.1, U26.7
unnamed: C95.1, U26.3
unnamed: R100.1, R102.2, U26.2
unnamed: R101.1, R103.2, U26.6
unnamed: C98.2, R100.2
unnamed: C99.2, R101.2
unnamed: C96.C, L26.1
unnamed: C97.C, L27.1
unnamed: C103.2, U28.9, Y10.X2
unnamed: C102.2, U28.17, Y10.X1
unnamed: C104.2, L28.1, U30.SLEEVE
unnamed: C107.A, R114.1, U29.1
unnamed: C108.A, R115.1, U29.7
unnamed: C106.1, U29.3
unnamed: R112.1, R114.2, U29.2
unnamed: R113.1, R115.2, U29.6
unnamed: C109.2, R112.2
unnamed: C110.2, R113.2
unnamed: C107.C, L29.1
unnamed: C108.C, L30.1
unnamed: C114.2, U31.9, Y11.X2
unnamed: C113.2, U31.17, Y11.X1
unnamed: C115.2, L31.1, U33.SLEEVE
unnamed: C118.A, R126.1, U32.1
unnamed: C119.A, R127.1, U32.7
unnamed: C117.1, U32.3
unnamed: R124.1, R126.2, U32.2
unnamed: R125.1, R127.2, U32.6
unnamed: C120.2, R124.2
unnamed: C121.2, R125.2
unnamed: C118.C, L32.1
unnamed: C119.C, L33.1
unnamed: C125.2, U34.9, Y12.X2
unnamed: C124.2, U34.17, Y12.X1
unnamed: C126.2, L34.1, U36.SLEEVE
unnamed: C129.A, R138.1, U35.1
unnamed: C130.A, R139.1, U35.7
unnamed: C128.1, U35.3
unnamed: R136.1, R138.2, U35.2
unnamed: R137.1, R139.2, U35.6
unnamed: C131.2, R136.2
unnamed: C132.2, R137.2
unnamed: C129.C, L35.1
unnamed: C130.C, L36.1
unnamed: C136.2, U37.9, Y13.X2
unnamed: C135.2, U37.17, Y13.X1
unnamed: C137.2, L37.1, U39.SLEEVE
unnamed: C140.A, R150.1, U38.1
unnamed: C141.A, R151.1, U38.7
unnamed: C139.1, U38.3
unnamed: R148.1, R150.2, U38.2
unnamed: R149.1, R151.2, U38.6
unnamed: C142.2, R148.2
unnamed: C143.2, R149.2
unnamed: C140.C, L38.1
unnamed: C141.C, L39.1
unnamed: C147.2, U40.9, Y14.X2
unnamed: C146.2, U40.17, Y14.X1
unnamed: C148.2, L40.1, U42.SLEEVE
unnamed: C151.A, R162.1, U41.1
unnamed: C152.A, R163.1, U41.7
unnamed: C150.1, U41.3
unnamed: R160.1, R162.2, U41.2
unnamed: R161.1, R163.2, U41.6
unnamed: C153.2, R160.2
unnamed: C154.2, R161.2
unnamed: C151.C, L41.1
unnamed: C152.C, L42.1
unnamed: C158.2, U43.9, Y15.X2
unnamed: C157.2, U43.17, Y15.X1
unnamed: C159.2, L43.1, U45.SLEEVE
unnamed: C162.A, R174.1, U44.1
unnamed: C163.A, R175.1, U44.7
unnamed: C161.1, U44.3
unnamed: R172.1, R174.2, U44.2
unnamed: R173.1, R175.2, U44.6
unnamed: C164.2, R172.2
unnamed: C165.2, R173.2
unnamed: C162.C, L44.1
unnamed: C163.C, L45.1
RA: L3.2, U4.RING
RA1: L6.2, U6.RING
RA2: L9.2, U9.RING
RA3: L12.2, U12.RING
RA4: L15.2, U15.RING
RA5: L18.2, U18.RING
RA6: L21.2, U21.RING
RA7: L24.2, U24.RING
RA8: L27.2, U27.RING
RA9: L30.2, U30.RING
RA10: L33.2, U33.RING
RA11: L36.2, U36.RING
RA12: L39.2, U39.RING
RA13: L42.2, U42.RING
RA14: L45.2, U45.RING
ROUT: C11.1, U1.13
ROUT1: C22.1, U2.13
ROUT2: C33.1, U7.13
ROUT3: C44.1, U10.13
ROUT4: C55.1, U13.13
ROUT5: C66.1, U16.13
ROUT6: C77.1, U19.13
ROUT7: C88.1, U22.13
ROUT8: C99.1, U25.13
ROUT9: C110.1, U28.13
ROUT10: C121.1, U31.13
ROUT11: C132.1, U34.13
ROUT12: C143.1, U37.13
ROUT13: C154.1, U40.13
ROUT14: C165.1, U43.13
SCLK: JP1.5, R10.2
SCLK1: JP2.5, R22.2
SCLK2: JP9.5, R34.2
SCLK3: JP13.5, R46.2
SCLK4: JP17.5, R58.2
SCLK5: JP21.5, R70.2
SCLK6: JP25.5, R82.2
SCLK7: JP29.5, R94.2
SCLK8: JP33.5, R106.2
SCLK9: JP37.5, R118.2
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

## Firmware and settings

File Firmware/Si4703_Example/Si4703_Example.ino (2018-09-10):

/*
 1-6-2011
 Spark Fun Electronics 2011
 Nathan Seidle
 
 This code is public domain but you buy me a beer if you use this and we meet someday (Beerware license).
 
 To use this code, connect the following 5 wires:
 Arduino : Si470x board
 3.3V : VCC
 GND : GND
 A5 : SCLK
 A4 : SDIO
 D2 : RST
 A0 : Trimpot (optional)
 
 Look for serial output at 57600bps.
 
 The Si4703 ACKs the first byte, and NACKs the 2nd byte of a read.
 
 1/18 - after much hacking, I suggest NEVER write to a register without first reading the contents of a chip.
 ie, don't updateRegisters without first readRegisters.
 
 This document was crucial: http://wenku.baidu.com/view/d6f0e6ee5ef7ba0d4a733b61.html
 It had a change on page 12 (write 0x8100 to 0x07) that allowed me to get the chip working..
 
 Be sure to see "AN243: Using RDS/RBDS with the Si4701/03" for more info about the extra info embedded in a broadcast signal.
 
 1/20/11 - Picking up FM stations from a plane flying over Portugal! Sweet! 93.9MHz sounds a little soft for my tastes,s but
 it's in Porteguese.
 
 ToDo:
 Display current status (from 0x0A) - done 1/20/11
 Add RDS decoding - works, sort of
 Volume Up/Down - done 1/20/11
 Mute toggle - done 1/20/11
 Tune Up/Down - done 1/20/11
 Read current channel (0xB0) - done 1/20/11
 Setup for Europe - done 1/20/11
 Seek up/down - done 1/25/11
 
 The Si4703 breakout does work with line out into a stereo or other amplifier. Be sure to test with different length 3.5mm
 cables. Too short of a cable may degrade reception.
 */

#include <Wire.h>

int STATUS_LED = 13;
int resetPin = 2;
int SDIO = A4; //SDA/A4 on Arduino
int SCLK = A5; //SCL/A5 on Arduino
char printBuffer[50];
uint16_t si4703_registers[16]; //There are 16 registers, each 16 bits large

#define FAIL  0
#define SUCCESS  1

#define SI4703 0x10 //0b._001.0000 = I2C address of Si4703 - note that the Wire function assumes non-left-shifted I2C address, not 0b.0010.000W
#define I2C_FAIL_MAX  10 //This is the number of attempts we will try to contact the device before erroring out

//#define IN_EUROPE //Use this define to setup European FM reception. I wuz there for a day during testing (TEI 2011).

#define SEEK_DOWN  0 //Direction used for seeking. Default is down
#define SEEK_UP  1

//Define the register names
#define DEVICEID 0x00
#define CHIPID  0x01
#define POWERCFG  0x02
#define CHANNEL  0x03
#define SYSCONFIG1  0x04
#define SYSCONFIG2  0x05
#define STATUSRSSI  0x0A
#define READCHAN  0x0B
#define RDSA  0x0C
#define RDSB  0x0D
#define RDSC  0x0E
#define RDSD  0x0F

//Register 0x02 - POWERCFG
#define SMUTE  15
#define DMUTE  14
#define SKMODE  10
#define SEEKUP  9
#define SEEK  8

//Register 0x03 - CHANNEL
#define TUNE  15

//Register 0x04 - SYSCONFIG1
#define RDS  12
#define DE  11

//Register 0x05 - SYSCONFIG2
#define SPACE1  5
#define SPACE0  4

//Register 0x0A - STATUSRSSI
#define RDSR  15
#define STC  14
#define SFBL  13
#define AFCRL  12
#define RDSS  11
#define STEREO  8

void setup() {                
  pinMode(13, OUTPUT);
  pinMode(A0, INPUT); //Optional trimpot for analog station control

  Serial.begin(57600);
  Serial.println();

  si4703_init(); //Init the Si4703 - we need to toggle SDIO before Wire.begin takes over.

}

void loop() {
  char option;
  char vol = 15;
  int currentChannel = 973; //Default the unit to a known good local radio station

  gotoChannel(currentChannel);

  while(1) {
    Serial.println();
    Serial.println("Si4703 Configuration");

    currentChannel = readChannel();
    sprintf(printBuffer, "Current station: %02d.%01dMHz", currentChannel / 10, currentChannel % 10);
    Serial.println(printBuffer);

#ifdef IN_EUROPE
    Serial.println("Configured for European Radio");
#endif

    Serial.println("1) Tune to 97.3");
    Serial.println("2) Mute On/Off");
    Serial.println("3) Display status");
    Serial.println("4) Seek up");
    Serial.println("5) Seek down");
    Serial.println("6) Poll for RDS");
    Serial.println("7) Display RDS radio text");
    Serial.println("r) Print registers");
    Serial.println("n) Print station name from RDS");
    Serial.println("8) Turn GPIO1 High");
    Serial.println("9) Turn GPIO1 Low");
    Serial.println("v) Volume");
    Serial.println("w) Tune up");
    Serial.println("s) Tune down");
    Serial.print(": ");

    while (!Serial.available());
    option = Serial.read();

    if(option == '1')  {
      Serial.println("Tune to 97.3");
      currentChannel = 973;
      //currentChannel = 1023;
      gotoChannel(currentChannel);
    }
    else if(option == '2') {
      Serial.println("Mute toggle");
      si4703_readRegisters();
      si4703_registers[POWERCFG] ^= (1<<DMUTE); //Toggle Mute bit
      si4703_updateRegisters();
    }
    else if(option == '3') {
      si4703_readRegisters();

      Serial.println();
      Serial.println("Radio Status:");

      if(si4703_registers[STATUSRSSI] & (1<<RDSR)){
        Serial.print(" (RDS Available)");

        byte blockerrors = (si4703_registers[STATUSRSSI] & 0x0600) >> 9; //Mask in BLERA
        if(blockerrors == 0) Serial.print (" (No RDS errors)");
        if(blockerrors == 1) Serial.print (" (1-2 RDS errors)");
        if(blockerrors == 2) Serial.print (" (3-5 RDS errors)");
        if(blockerrors == 3) Serial.print (" (6+ RDS errors)");
      }
      else
        Serial.print(" (No RDS)");

      if(si4703_registers[STATUSRSSI] & (1<<STC)) Serial.print(" (Tune Complete)");
      if(si4703_registers[STATUSRSSI] & (1<<SFBL)) 
        Serial.print(" (Seek Fail)");
      else
        Serial.print(" (Seek Successful!)");
      if(si4703_registers[STATUSRSSI] & (1<<AFCRL)) Serial.print(" (AFC/Invalid Channel)");
      if(si4703_registers[STATUSRSSI] & (1<<RDSS)) Serial.print(" (RDS Synch)");

      if(si4703_registers[STATUSRSSI] & (1<<STEREO)) 
        Serial.print(" (Stereo!)");
      else
        Serial.print(" (Mono)");

      byte rssi = si4703_registers[STATUSRSSI] & 0x00FF; //Mask in RSSI
      Serial.print(" (RSSI=");
      Serial.print(rssi, DEC);
      Serial.println(" of 75)");
    }
    else if(option == '4') {
      seek(SEEK_UP);
    }
    else if(option == '5') {
      seek(SEEK_DOWN);
    }
    else if(option == '6') {
      Serial.println("Poll RDS - x to exit");
      while(1) {
        if(Serial.available() > 0)
          if(Serial.read() == 'x') break;

        si4703_readRegisters();
        if(si4703_registers[STATUSRSSI] & (1<<RDSR)){
          Serial.println("We have RDS!");
          byte Ah, Al, Bh, Bl, Ch, Cl, Dh, Dl;
          Ah = (si4703_registers[RDSA] & 0xFF00) >> 8;
          Al = (si4703_registers[RDSA] & 0x00FF);

          Bh = (si4703_registers[RDSB] & 0xFF00) >> 8;
          Bl = (si4703_registers[RDSB] & 0x00FF);

          Ch = (si4703_registers[RDSC] & 0xFF00) >> 8;
          Cl = (si4703_registers[RDSC] & 0x00FF);

          Dh = (si4703_registers[RDSD] & 0xFF00) >> 8;
          Dl = (si4703_registers[RDSD] & 0x00FF);

          Serial.print("RDS: ");
          Serial.print(Ah);
          Serial.print(Al);
          Serial.print(Bh);
          Serial.print(Bl);
          Serial.print(Ch);
          Serial.print(Cl);
          Serial.print(Dh);
          Serial.print(Dl);
          Serial.println(" !");

          delay(40); //Wait for the RDS bit to clear
        }
        else {
          Serial.println("No RDS");
          delay(30); //From AN230, using the polling method 40ms should be sufficient amount of time between checks
        }
        //delay(500);
      }
    }
    else if(option == '7') {
      Serial.println("Poll RDS - x to exit");

      char radioTextData[64];
      char* pointerToRadioTextData = radioTextData;

      memset(radioTextData, ' ', sizeof(radioTextData));

      while (1) {
        if (Serial.available() > 0)
          if (Serial.read() == 'x') break;

        si4703_readRegisters();
        if(si4703_registers[STATUSRSSI] & (1<<RDSR)){
          if (isValidRdsData())
          {
            if (isRadioTextData())
            {
              // set each element of the radio text data as we get it
              setRadioTextData(pointerToRadioTextData);

              // now write the radio text to serial
              for (short i = 0; i < sizeof(radioTextData); i++) {
                Serial.print(radioTextData[i]);
              }
              Serial.println(" ");
            }
          }
          delay(40); //Wait for the RDS bit to clear
        }
        else {
          delay(40); //From AN230, using the polling method 40ms should be sufficient amount of time between checks
        }
      }
    }
    else if(option == '8') {
      Serial.println("GPIO1 High");
      si4703_registers[SYSCONFIG1] |= (1<<1) | (1<<0);
      si4703_updateRegisters();
    }
    else if(option == '9') {
      Serial.println("GPIO1 Low");
      si4703_registers[SYSCONFIG1] &= ~(1<<0);
      si4703_updateRegisters();
    }
    else if(option == 'r') {
      Serial.println("Print registers");
      si4703_printRegisters();
    }
    else if(option == 'n') {
      Serial.println("Print station name - x to exit");
      char stationName[8];
      char* pointerToStationNameData = stationName;

      memset(stationName, ' ', sizeof(stationName));

      while (1) {
        if (Serial.available() > 0)
          if (Serial.read() == 'x') break;

        si4703_readRegisters();
        if(si4703_registers[STATUSRSSI] & (1<<RDSR)){
          if (isValidStationNameData())
          {
            if (isStationNameData())
            {
              // set each element of the radio station name as we get it
              setStationNameData(pointerToStationNameData);

              // now write the radio text to serial
              for (short i = 0; i < sizeof(stationName); i++) {
                Serial.print(stationName[i]);
              }
              Serial.println(" ");
            }
          }
          delay(40); //Wait for the RDS bit to clear
        }
        else {
          delay(40); //From AN230, using the polling method 40ms should be sufficient amount of time between checks
        }
      }
    }
    else if(option == 't') {
      Serial.println("Trim pot tuning");
      while(1) {
        if(Serial.available())
          if(Serial.read() == 'x') break;

        int trimpot = 0;
        for(int x = 0 ; x < 16 ; x++)
          trimpot += analogRead(A0);
        trimpot /= 16; //Take average of trimpot reading

        Serial.print("Trim: ");
        Serial.print(trimpot);
        trimpot = map(trimpot, 0, 1023, 875, 1079); //Convert the trimpot value to a valid station
        Serial.print(" station: ");
        Serial.println(trimpot);
        if(trimpot != currentChannel) {
          currentChannel = trimpot;
          gotoChannel(currentChannel);
        }

        delay(100);
      }
    }
    else if(option == 'v') {

      byte current_vol;

      Serial.println();
      Serial.println("Volume:");
      Serial.println("+) Up");
      Serial.println("-) Down");
      Serial.println("x) Exit");
      while(1){
        if(Serial.available()){
          option = Serial.read();
          if(option == '+') {
            si4703_readRegisters(); //Read the current register set
            current_vol = si4703_registers[SYSCONFIG2] & 0x000F; //Read the current volume level
            if(current_vol < 16) current_vol++; //Limit max volume to 0x000F
            si4703_registers[SYSCONFIG2] &= 0xFFF0; //Clear volume bits
            si4703_registers[SYSCONFIG2] |= current_vol; //Set new volume
            si4703_updateRegisters(); //Update
            Serial.print("Volume: ");
            Serial.println(current_vol, DEC);
          }
          if(option == '-') {
            si4703_readRegisters(); //Read the current register set
            current_vol = si4703_registers[SYSCONFIG2] & 0x000F; //Read the current volume level
            if(current_vol > 0) current_vol--; //You can't go lower than zero
            si4703_registers[SYSCONFIG2] &= 0xFFF0; //Clear volume bits
            si4703_registers[SYSCONFIG2] |= current_vol; //Set new volume
            si4703_updateRegisters(); //Update
            Serial.print("Volume: ");
            Serial.println(current_vol, DEC);
          }
          else if(option == 'x') break;
        }
      }
    }

    else if(option == 'w') {
      currentChannel = readChannel();
#ifdef IN_EUROPE
      currentChannel += 1; //Increase channel by 100kHz
#else
      currentChannel += 2; //Increase channel by 200kHz
#endif
      gotoChannel(currentChannel);
    }
    else if(option == 's') {
      currentChannel = readChannel();
#ifdef IN_EUROPE
      currentChannel -= 1; //Decreage channel by 100kHz
#else
      currentChannel -= 2; //Decrease channel by 200kHz
#endif
      gotoChannel(currentChannel);
    }
    else {
      Serial.print("Choice = ");
      Serial.println(option);
    }
  }
}

//Given a channel, tune to it
//Channel is in MHz, so 973 will tune to 97.3MHz
//Note: gotoChannel will go to illegal channels (ie, greater than 110MHz)
//It's left to the user to limit these if necessary
//Actually, during testing the Si4703 seems to be internally limiting it at 87.5. Neat.
void gotoChannel(int newChannel){
  //Freq(MHz) = 0.200(in USA) * Channel + 87.5MHz
  //97.3 = 0.2 * Chan + 87.5
  //9.8 / 0.2 = 49
  newChannel *= 10; //973 * 10 = 9730
  newChannel -= 8750; //9730 - 8750 = 980

#ifdef IN_EUROPE
    newChannel /= 10; //980 / 10 = 98
#else
  newChannel /= 20; //980 / 20 = 49
#endif

  //These steps come from AN230 page 20 rev 0.5
  si4703_readRegisters();
  si4703_registers[CHANNEL] &= 0xFE00; //Clear out the channel bits
  si4703_registers[CHANNEL] |= newChannel; //Mask in the new channel
  si4703_registers[CHANNEL] |= (1<<TUNE); //Set the TUNE bit to start
  si4703_updateRegisters();

  //delay(60); //Wait 60ms - you can use or skip this delay

  //Poll to see if STC is set
  while(1) {
    si4703_readRegisters();
    if( (si4703_registers[STATUSRSSI] & (1<<STC)) != 0) break; //Tuning complete!
    Serial.println("Tuning");
  }

  si4703_readRegisters();
  si4703_registers[CHANNEL] &= ~(1<<TUNE); //Clear the tune after a tune has completed
  si4703_updateRegisters();

  //Wait for the si4703 to clear the STC as well
  while(1) {
    si4703_readRegisters();
    if( (si4703_registers[STATUSRSSI] & (1<<STC)) == 0) break; //Tuning complete!
    Serial.println("Waiting...");
  }
}

//Reads the current channel from READCHAN
//Returns a number like 973 for 97.3MHz
int readChannel(void) {
  si4703_readRegisters();
  int channel = si4703_registers[READCHAN] & 0x03FF; //Mask out everything but the lower 10 bits

#ifdef IN_EUROPE
  //Freq(MHz) = 0.100(in Europe) * Channel + 87.5MHz
  //X = 0.1 * Chan + 87.5
  channel *= 1; //98 * 1 = 98 - I know this line is silly, but it makes the code look uniform
#else
  //Freq(MHz) = 0.200(in USA) * Channel + 87.5MHz
  //X = 0.2 * Chan + 87.5
  channel *= 2; //49 * 2 = 98
#endif

  channel += 875; //98 + 875 = 973
  return(channel);
}

//Seeks out the next available station
//Returns the freq if it made it
//Returns zero if failed
byte seek(byte seekDirection){
  si4703_readRegisters();

  //Set seek mode wrap bit
  //si4703_registers[POWERCFG] |= (1<<SKMODE); //Allow wrap
  si4703_registers[POWERCFG] &= ~(1<<SKMODE); //Disallow wrap - if you disallow wrap, you may want to tune to 87.5 first

  if(seekDirection == SEEK_DOWN) si4703_registers[POWERCFG] &= ~(1<<SEEKUP); //Seek down is the default upon reset
  else si4703_registers[POWERCFG] |= 1<<SEEKUP; //Set the bit to seek up

  si4703_registers[POWERCFG] |= (1<<SEEK); //Start seek

  si4703_updateRegisters(); //Seeking will now start

  //Poll to see if STC is set
  while(1) {
    si4703_readRegisters();
    if((si4703_registers[STATUSRSSI] & (1<<STC)) != 0) break; //Tuning complete!

    Serial.print("Trying station:");
    Serial.println(readChannel());
  }

  si4703_readRegisters();
  int valueSFBL = si4703_registers[STATUSRSSI] & (1<<SFBL); //Store the value of SFBL
  si4703_registers[POWERCFG] &= ~(1<<SEEK); //Clear the seek bit after seek has completed
  si4703_updateRegisters();

  //Wait for the si4703 to clear the STC as well
  while(1) {
    si4703_readRegisters();
    if( (si4703_registers[STATUSRSSI] & (1<<STC)) == 0) break; //Tuning complete!
    Serial.println("Waiting...");
  }

  if(valueSFBL) { //The bit was set indicating we hit a band limit or failed to find a station
    Serial.println("Seek limit hit"); //Hit limit of band during seek
    return(FAIL);
  }

  Serial.println("Seek complete"); //Tuning complete!
  return(SUCCESS);
}

//To get the Si4703 inito 2-wire mode, SEN needs to be high and SDIO needs to be low after a reset
//The breakout board has SEN pulled high, but also has SDIO pulled high. Therefore, after a normal power up
//The Si4703 will be in an unknown state. RST must be controlled
void si4703_init(void) {
  Serial.println("Initializing I2C and Si4703");
  
  pinMode(resetPin, OUTPUT);
  pinMode(SDIO, OUTPUT); //SDIO is connected to A4 for I2C
  digitalWrite(SDIO, LOW); //A low SDIO indicates a 2-wire interface
  digitalWrite(resetPin, LOW); //Put Si4703 into reset
  delay(1); //Some delays while we allow pins to settle
  digitalWrite(resetPin, HIGH); //Bring Si4703 out of reset with SDIO set to low and SEN pulled high with on-board resistor
  delay(1); //Allow Si4703 to come out of reset

  Wire.begin(); //Now that the unit is reset and I2C inteface mode, we need to begin I2C

  si4703_readRegisters(); //Read the current register set
  //si4703_registers[0x07] = 0xBC04; //Enable the oscillator, from AN230 page 9, rev 0.5 (DOES NOT WORK, wtf Silicon Labs datasheet?)
  si4703_registers[0x07] = 0x8100; //Enable the oscillator, from AN230 page 9, rev 0.61 (works)
  si4703_updateRegisters(); //Update

  delay(500); //Wait for clock to settle - from AN230 page 9

  si4703_readRegisters(); //Read the current register set
  si4703_registers[POWERCFG] = 0x4001; //Enable the IC
  //  si4703_registers[POWERCFG] |= (1<<SMUTE) | (1<<DMUTE); //Disable Mute, disable softmute
  si4703_registers[SYSCONFIG1] |= (1<<RDS); //Enable RDS

#ifdef IN_EUROPE
    si4703_registers[SYSCONFIG1] |= (1<<DE); //50kHz Europe setup
  si4703_registers[SYSCONFIG2] |= (1<<SPACE0); //100kHz channel spacing for Europe
#else
  si4703_registers[SYSCONFIG2] &= ~(1<<SPACE1 | 1<<SPACE0) ; //Force 200kHz channel spacing for USA
#endif

  si4703_registers[SYSCONFIG2] &= 0xFFF0; //Clear volume bits
  si4703_registers[SYSCONFIG2] |= 0x0001; //Set volume to lowest
  si4703_updateRegisters(); //Update

  delay(110); //Max powerup time, from datasheet page 13
}

//Write the current 9 control registers (0x02 to 0x07) to the Si4703
//It's a little weird, you don't write an I2C addres
//The Si4703 assumes you are writing to 0x02 first, then increments
byte si4703_updateRegisters(void) {

  Wire.beginTransmission(SI4703);
  //A write command automatically begins with register 0x02 so no need to send a write-to address
  //First we send the 0x02 to 0x07 control registers
  //In general, we should not write to registers 0x08 and 0x09
  for(int regSpot = 0x02 ; regSpot < 0x08 ; regSpot++) {
    byte high_byte = si4703_registers[regSpot] >> 8;
    byte low_byte = si4703_registers[regSpot] & 0x00FF;

    Wire.write(high_byte); //Upper 8 bits
    Wire.write(low_byte); //Lower 8 bits
  }

  //End this transmission
  byte ack = Wire.endTransmission();
  if(ack != 0) { //We have a problem! 
    Serial.print("Write Fail:"); //No ACK!
    Serial.println(ack, DEC); //I2C error: 0 = success, 1 = data too long, 2 = rx NACK on address, 3 = rx NACK on data, 4 = other error
    return(FAIL);
  }

  return(SUCCESS);
}

//Read the entire register control set from 0x00 to 0x0F
void si4703_readRegisters(void){

  //Si4703 begins reading from register upper register of 0x0A and reads to 0x0F, then loops to 0x00.
  Wire.requestFrom(SI4703, 32); //We want to read the entire register set from 0x0A to 0x09 = 32 bytes.

  //Remember, register 0x0A comes in first so we have to shuffle the array around a bit
  for(int x = 0x0A ; ; x++) { //Read in these 32 bytes
    if(x == 0x10) x = 0; //Loop back to zero
    si4703_registers[x] = Wire.read() << 8;
    si4703_registers[x] |= Wire.read();
    if(x == 0x09) break; //We're done!
  }
}

void si4703_printRegisters(void) {
  //Read back the registers
  si4703_readRegisters();

  //Print the response array for debugging
  for(int x = 0 ; x < 16 ; x++) {
    sprintf(printBuffer, "Reg 0x%02X = 0x%04X", x, si4703_registers[x]);
    Serial.println(printBuffer);
  }
}

boolean isValidAsciiBasicCharacterSet(byte rdsData)
{
  return rdsData >= 32 && rdsData <= 127;
}

boolean isValidRdsData() {

  byte blockErrors = (byte)((si4703_registers[STATUSRSSI] & 0x0600) >> 9); //Mask in BLERA;

  byte Ch = (si4703_registers[RDSC] & 0xFF00) >> 8;
  byte Cl = (si4703_registers[RDSC] & 0x00FF);

  byte Dh = (si4703_registers[RDSD] & 0xFF00) >> 8;
  byte Dl = (si4703_registers[RDSD] & 0x00FF);

  return blockErrors == 0 && isValidAsciiBasicCharacterSet(Dh) && isValidAsciiBasicCharacterSet(Dl) && isValidAsciiBasicCharacterSet(Ch) && isValidAsciiBasicCharacterSet(Cl);
}

boolean isValidStationNameData() {

  byte blockErrors = (byte)((si4703_registers[STATUSRSSI] & 0x0600) >> 9); //Mask in BLERA;

  byte Dh = (si4703_registers[RDSD] & 0xFF00) >> 8;
  byte Dl = (si4703_registers[RDSD] & 0x00FF);

  return blockErrors == 0 && isValidAsciiBasicCharacterSet(Dh) && isValidAsciiBasicCharacterSet(Dl);
}

boolean isRadioTextData(void) {
  return (si4703_registers[RDSB] >> 11) == 4 || (si4703_registers[RDSB] >> 11) == 5;
}

boolean isStationNameData(void) {
  return (si4703_registers[RDSB] >> 11) == 0 || (si4703_registers[RDSB] >> 11) == 1;
}
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

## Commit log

2013-06-28 Initial file upload for v12
    [Si470x-Eval.brd, Si470x-Eval.sch]
2013-12-13 Hardware changes to 0603 footprints and OSHW logo.
    [Si470x-Eval.brd, Si470x-Eval.sch]
2014-05-19 fixing I2C breakout order, adding board name to file
    [Si4703_Eval.brd, Si4703_Eval.sch]
2014-05-19 Fixing labels for 3.3V and GND
    [Si4703_Eval.brd]
2014-06-30 Fixing review complaints on version number and upside down ground on schematic
    [Si4703_Eval.brd, Si4703_Eval.sch]
2014-07-01 created panel v13
    [Si4703-Eval-Panel-v13.brd, Si4703_Eval.brd]
2015-05-14 Updating repo structure, adding documentation links, fixing names
    [Si470x-Eval.sch, SparkFun_Si4703_Eval_Board.brd, SparkFun_Si4703_Eval_Board.sch]
2015-05-14 Squashed 'Libraries/Arduino/' content from commit 9eac801
    git-subtree-dir: Libraries/Arduino
    git-subtree-split: 9eac801e8865f5b5235ab0d2657a47cae651a9bb
2017-10-08 Added functions to print out RDS and station name data.
2018-02-22 Copy of the Arduino library source.
    This code is unchanged, and will not currently compile on the
    Raspberry Pi.
2018-02-22 Cherry picked the RPi port from the rpi-si4703 project.
    The [rpi-si4703](https://github.com/cthoma/rpi-si4703.git) project
    is a Raspberry Pi port of the Arduino library from this repository.
    This change is a manual cherry-picking of that projects source
    at the a7344f425c5d3a8c5d83fe6e2a2954fc208eba74 commit with minor
    changes to correct file names. The Raspberry Pi port was done by
    thoma.christoph@gmx.at.
2018-02-24 Deleted si4703_init and si4703_exit.
    Moved their implementation (unchanged) into powerOn and powerOff
    respectively.
2018-02-24 Using correct I2C device file.
    This isn't really correct yet.
2018-02-24 Switched to tuning radio using MHz expressed with a float.
    Previously used a human readable integer "channel", like 885,
    which corresponded to 88.5 MHz, but was converted to a different
    "register channel" used by the Si4703. This changes switches to
    an even more human readable "frequency" (i.e. 88.), and the name
    "channel" is no longer overridden - it always means the Si4703
    register channel format (which varies by region).
2018-02-24 Changed register variable name: registers_ → shadow_reg_.
    shadow_reg is what is used in the AN230 Programmers Guide, and
    it more clearly communicates that these are a copy of the actual
    chip registers.
    Additionally minor comment/formatting tweaks.
2018-02-24 Improved printRegisters.
    printRegisters now decodes registers and prints more than just their
    numerical values. In doing so also switched to C++ iostream for
    output.
2018-02-25 Spawning thread to read RDS data.
    This change will automatically spawn a thread when the radio is
    powered on. A condition variable returned by rdsCV() can be used
    to receive a signal that new RDS data has been received. At any
    time calling getRDS() will copy the current RDS text to the
    supplied buffer.
    The RDS thread is automatically terminated when the radio is
    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
2018-09-12 Removed SCT Polling
    Enabled SCT interrupt and removed polling to prevent noise on bus from causing errors while tuning. Updated example code to reflect these changes.

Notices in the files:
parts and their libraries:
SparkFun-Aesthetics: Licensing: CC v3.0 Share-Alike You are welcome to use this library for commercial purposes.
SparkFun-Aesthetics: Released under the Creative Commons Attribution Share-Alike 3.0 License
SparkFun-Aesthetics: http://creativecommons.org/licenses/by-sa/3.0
